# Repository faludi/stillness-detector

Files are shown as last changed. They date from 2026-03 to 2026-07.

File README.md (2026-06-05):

The Stillness Detector senses presence and motion to determine if there is a person standing in front of it and whether that person is currently standing still. It is intended to provide a trigger to interactive art pieces that require stillness rather than action from the viewer. 

See the [DOCUMENTATION](DOCUMENTATION.md) for more information.

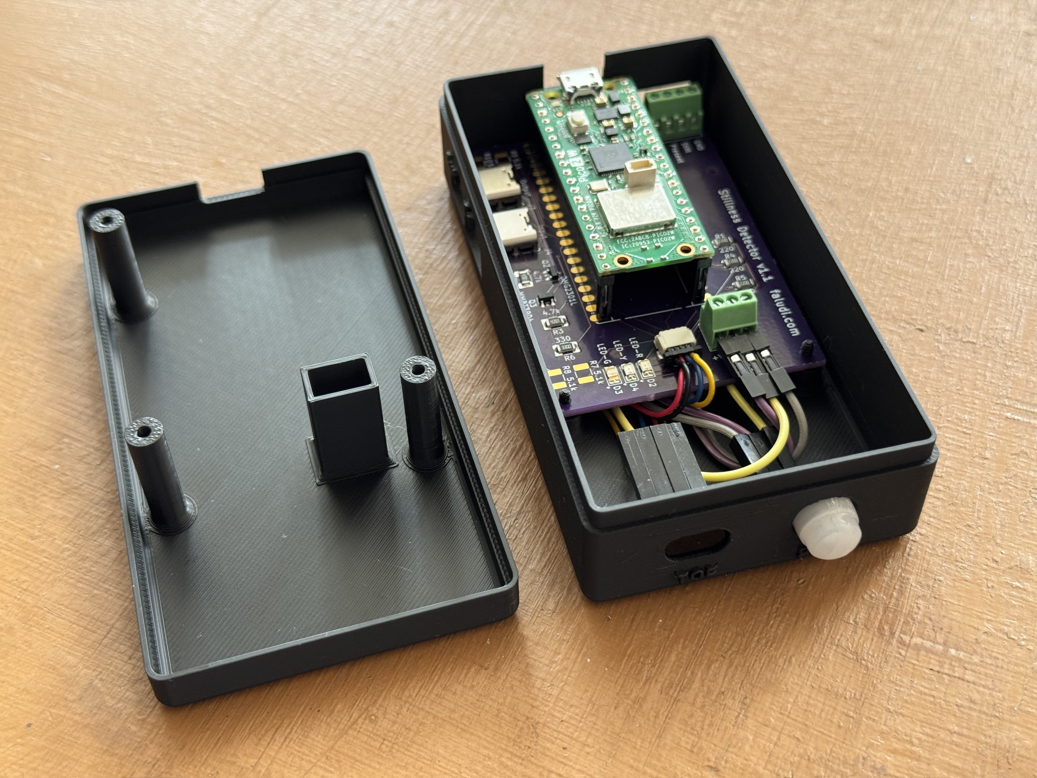
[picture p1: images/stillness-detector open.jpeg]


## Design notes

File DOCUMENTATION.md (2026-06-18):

# Stillness Detector – Documentation

---

## Overview

The **Stillness Detector** is an interactive sensor system that detects whether a person is present and standing still. It is intended for triggering interactive art pieces or installations **only** when a viewer is standing motionless in front of the artwork. The device uses:

- A **time-of-flight distance sensor** (VL53L1X) to measure distance in millimeters
- A **passive infrared (PIR) motion sensor** to detect heat signatures
- A **Raspberry Pi Pico 2** microcontroller to run the logic
- **Status LEDs** and **digital outputs** to trigger external devices (art installations, lights, etc.)

---

## Hardware Quickstart

### *See [Hardware](#hardware) section for design files*

<figure>
    
    <figcaption>Stillness Detector with lid open</figcaption>
</figure>

<figure>
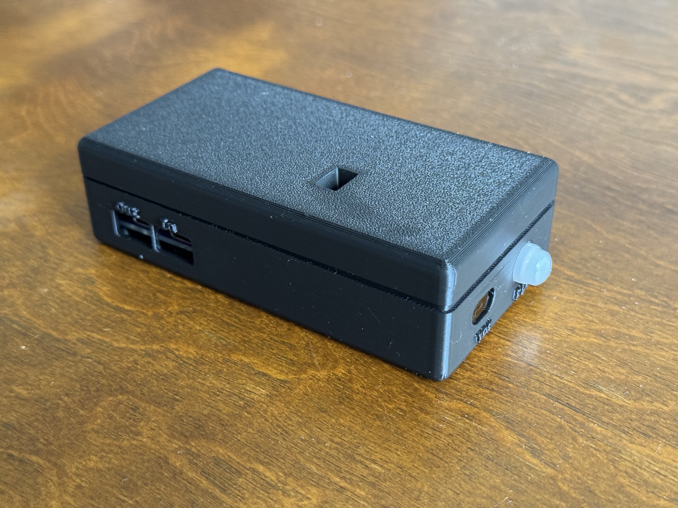
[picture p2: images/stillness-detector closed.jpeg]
    
    <figcaption>Stillness Detector with lid closed</figcaption>
</figure>

1. Power the stillness detector via its USB-micro connector labled "Power"
<figure>
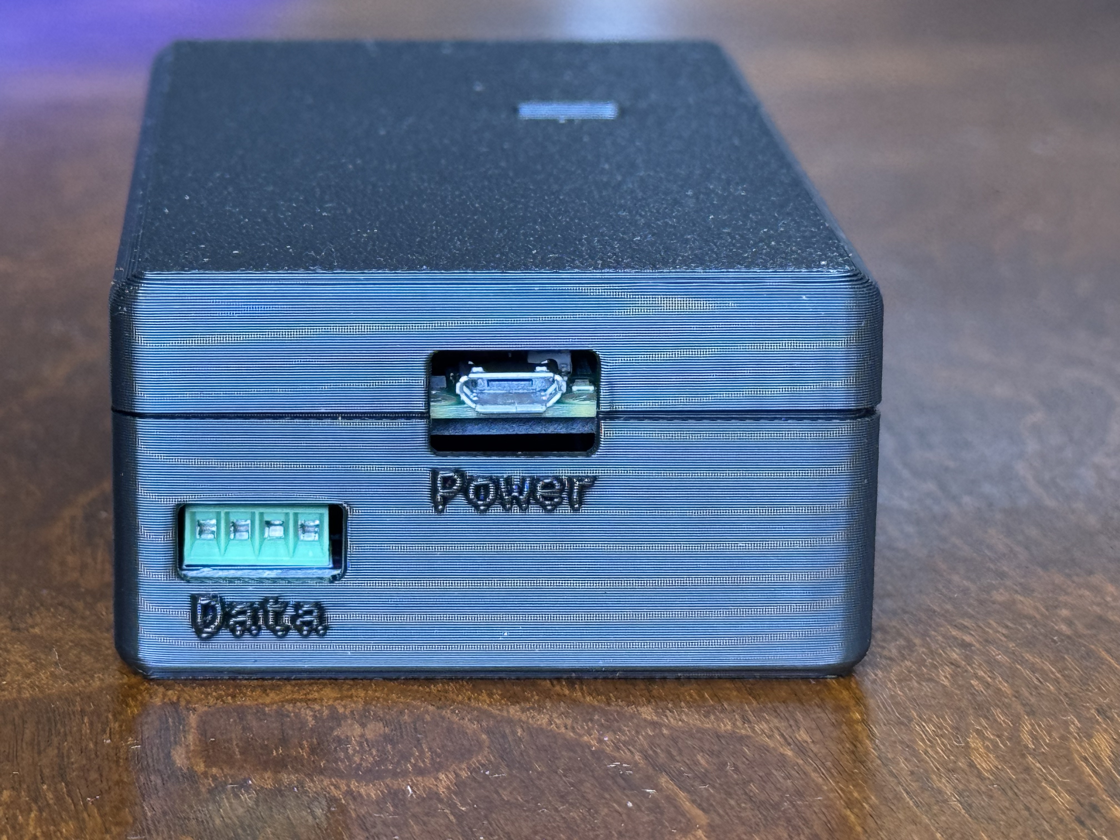
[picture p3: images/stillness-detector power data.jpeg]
    
    <figcaption>Stillness Detector power and data ports</figcaption>
</figure>

2. For controlling USB-C power, attach a power supply to the USB-C port marked "In", and a display device to the USB-C port marked "Out". Your display device will be powered whenever stillness is detected.
<figure>
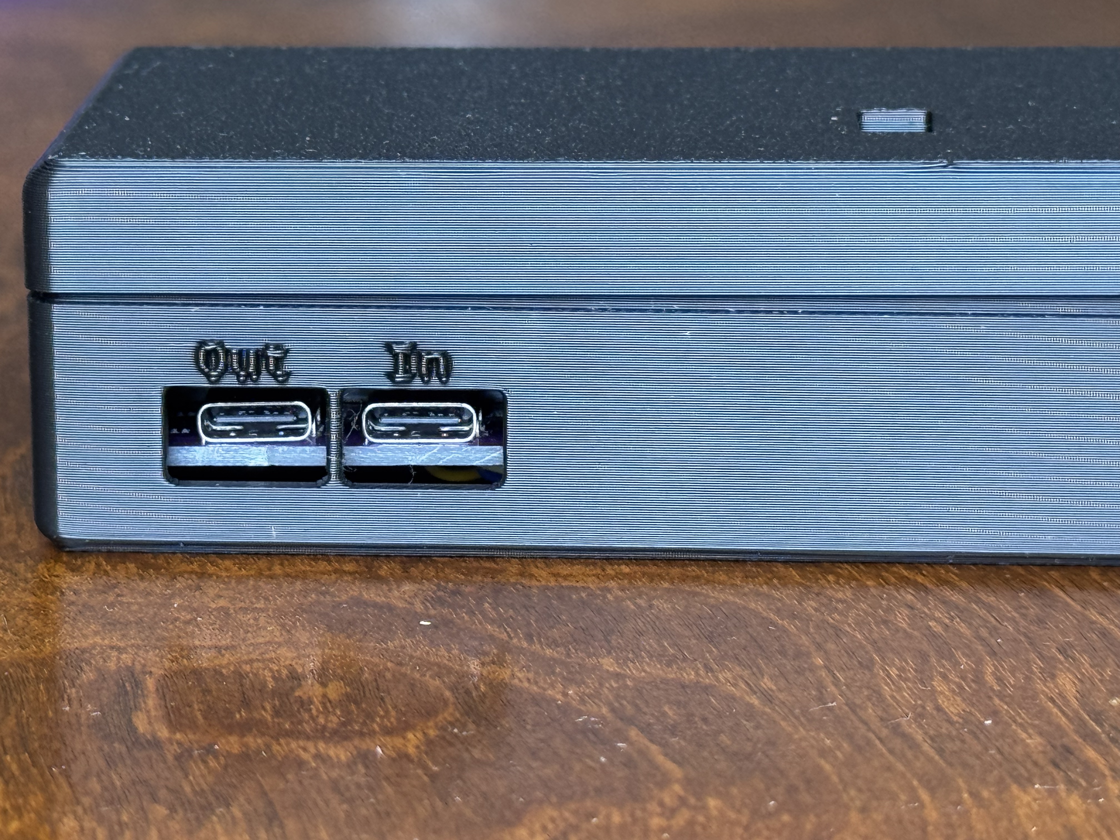
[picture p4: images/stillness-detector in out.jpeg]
    
    <figcaption>Stillness Detector USB-C power control input & output</figcaption>
</figure>

3. For controlling external microcontrollers, attach wires to the "Data" connector. At a minimum use "GND" for common ground and "Still" for output when stillness is detected. You can also use "Absent" which will be active when no person is detected, and "Present" which will be active when a person has been detected but they are not still yet.
<figure>
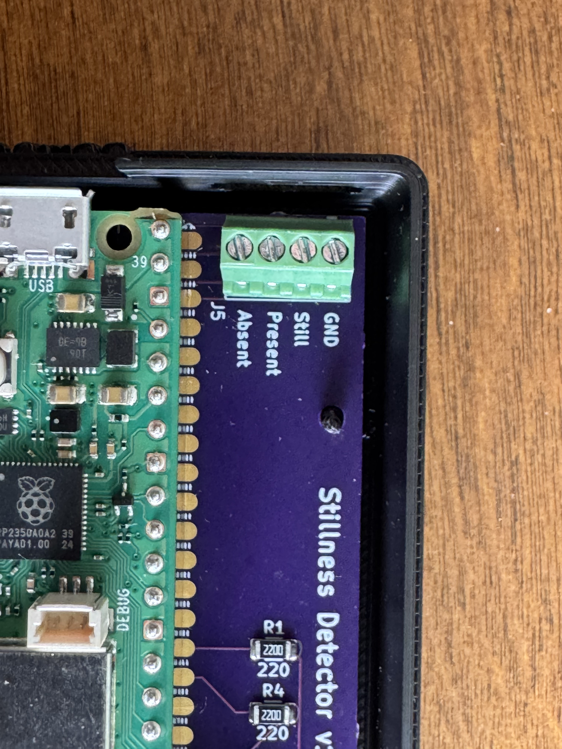
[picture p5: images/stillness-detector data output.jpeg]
    
    <figcaption>Stillness Detector data output connectors</figcaption>
</figure>

4. Orient the Stillness Detector so that that time-of-flight sensor and passive infrared sensor are pointed towards where the viewer will be standing.
<figure>
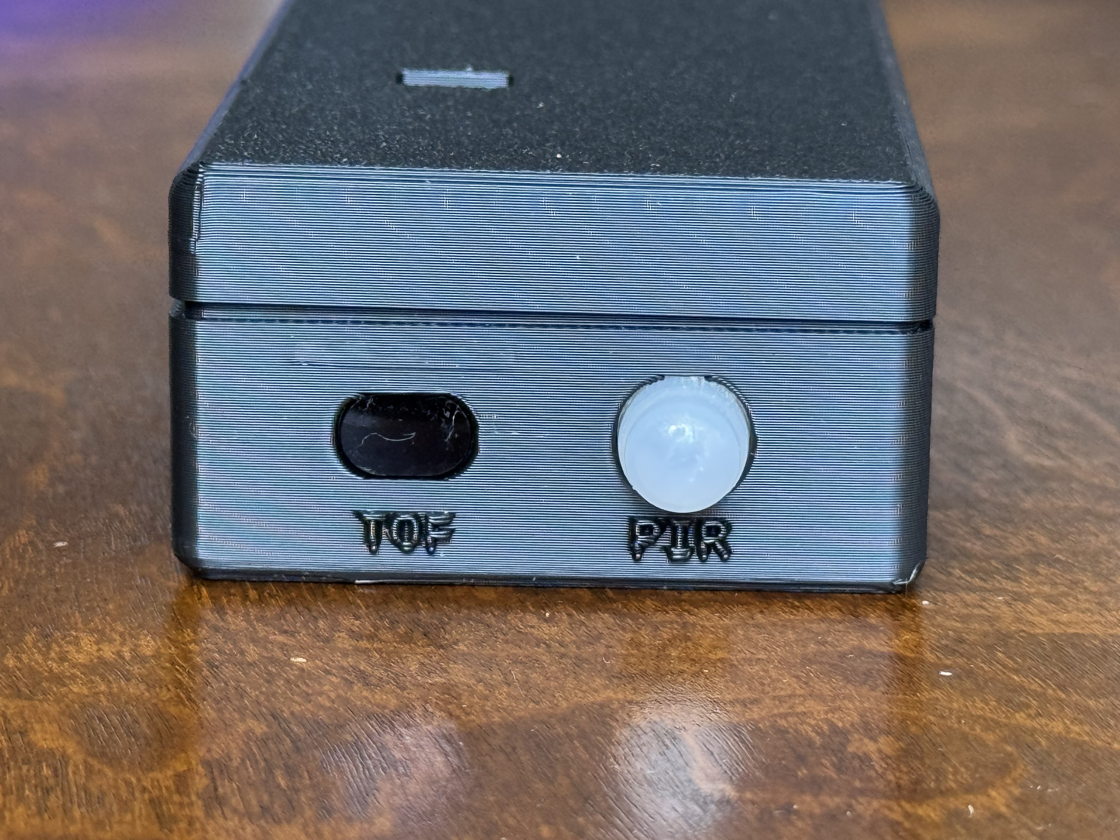
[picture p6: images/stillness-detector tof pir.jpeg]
    
    <figcaption>Stillness Detector time of flight and passive infrared sensors</figcaption>
</figure>

Inside the Stillness Detector is a Raspberry Pi Pico 2 WH with a custom circuit board and sensors.
<figure>
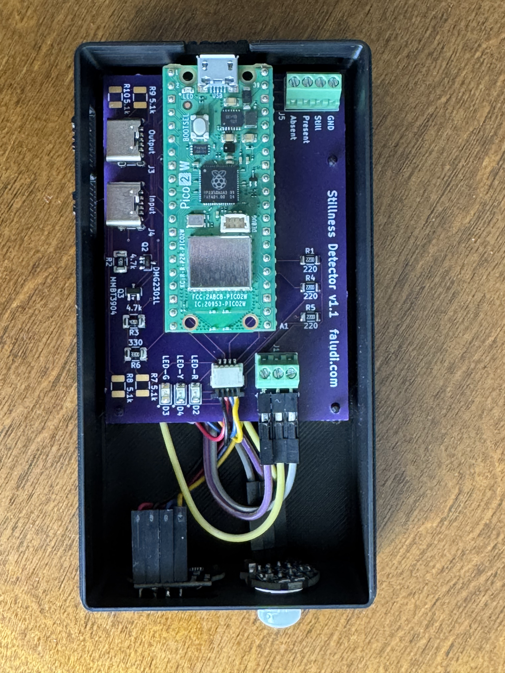
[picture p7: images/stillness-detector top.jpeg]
    
    <figcaption>Stillness Detector top view</figcaption>
</figure>

There are three output LEDs that indicate the detection state, Red when nobody is detected, yellow when a person is present but not yet still, green when they have settled and are motionless. The internal connectors for the sensors are also shown. These are useful if you want to place the sensors outside of the enclosure and need to extend the connector wires. 
<figure>
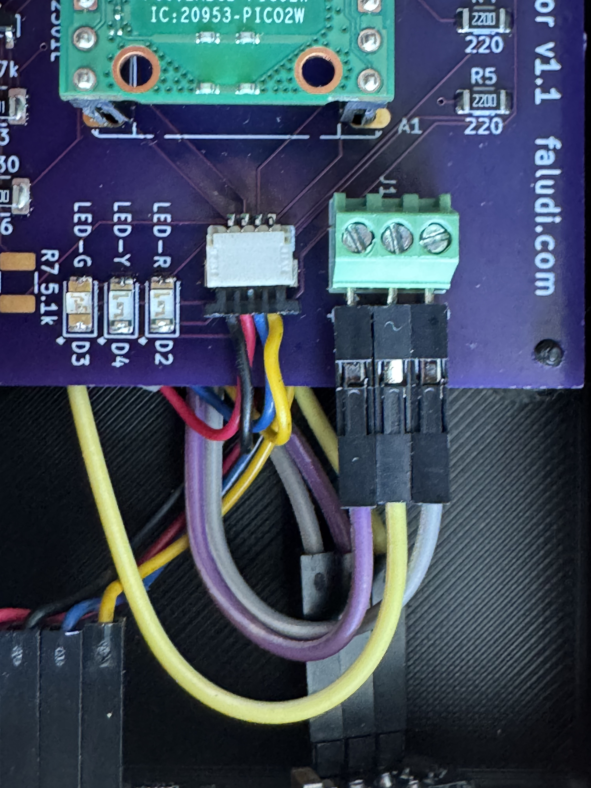
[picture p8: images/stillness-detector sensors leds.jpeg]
    
    <figcaption>Stillness Detector sensor connectors and status LEDs</figcaption>
</figure>

## Software Quickstart

### Installation

1. **Download MicroPython firmware** onto your Pico 2:
   - Visit [micropython.org/download/rp2350](https://micropython.org/download/rp2350)
   - Hold `BOOTSEL` button, plug in USB, drag `.uf2` file to mount

2. **Copy files** to the Pico 2:
   ```
   vl53l1x.py         (sensor driver)
   settings.py        (configuration)
   main.py            (main program)
   ```

3. **Run the program:**
   - The Pico 2 will auto-run `main.py` on startup
   - Or use a serial terminal (e.g., Thonny IDE) and press Ctrl+D to reload

4. **Verify:**
   - Green status LED should blink briefly on startup
   - Aim your hand at the distance sensor; you should see serial output with distance readings

---

## Files & Entry Points

**Repository Structure**

```
stillness-detector/
├── main.py              # Main program logic and event loop
├── vl53l1x.py           # VL53L1X sensor driver (time-of-flight)
├── settings.py          # User-configurable parameters
├── README.md            # Quick reference
├── DOCUMENTATION.md     # This file
├── hardware/            # CAD and circuit design files
│   ├── Stillness_Detector_Enclosure_v1.0.scad
│   ├── stillness-detector.kicad_pcb
│   └── stillness-detector.kicad_sch
└── images/              # Diagrams and photos
```

### File Roles at a Glance

- **`main.py`**: Entry point. Initializes hardware, reads sensors in a loop, applies logic to determine presence/stillness state, and sets output pins.
- **`vl53l1x.py`**: Time-of-flight sensor driver. Handles I2C communication and distance measurements.
- **`settings.py`**: Tuning parameters for sensitivity, delay, and mode presets.

---

## Code Walkthrough

### 1. Initialization (main.py)

When the Pico 2 boots, `main.py` sets up all hardware components. Here's what happens:

**Sensor Setup**

```python
from machine import Pin, I2C
from vl53l1x import VL53L1X
import settings

# Initialize I2C (bus 0 on Pico 2)
i2c = I2C(0)

# Create sensor object; this establishes I2C communication
time_of_flight = VL53L1X(i2c)
```

**What this does:**
- `I2C(0)` creates an I2C bus using GPIO4 (SDA) and GPIO5 (SCL).
- `VL53L1X(i2c)` initializes the sensor driver and sends startup commands to the sensor.

**Why it's written this way:**
- The sensor needs I2C to communicate; both SDA and SCL are on specific pins.
- Wrapping in a try/except (in the real code) allows retries if the sensor isn't ready.

**Pin & LED Setup**

```python
class HardwareInterface:
    """
    Manages all hardware components for the stillness detector.
    
    This class encapsulates:
    - Motion sensor (PIR)
    - Status LED (onboard)
    - RGB LED indicator
    - Digital output pins for external devices
    """
    def __init__(self):
        self.motion_sensor = Pin(PIR_PIN, Pin.IN)
        self.status_led = Pin(STATUS_LED_PIN, Pin.OUT)
        self.rgb_leds = {
            "red": Pin(RED_LED_PIN, Pin.OUT),
            "green": Pin(GREEN_LED_PIN, Pin.OUT),
            "yellow": Pin(YELLOW_LED_PIN, Pin.OUT),
        }
        self.outputs = {
            "absent": Pin(ABSENT_OUTPUT_PIN, Pin.OUT),
            "present": Pin(PRESENT_OUTPUT_PIN, Pin.OUT),
            "still": Pin(STILL_OUTPUT_PIN, Pin.OUT),
        }
```

**What this does:**
- Wraps all pin definitions in a class for organization.
- Sets up three categories: input (motion sensor), debug LEDs, and output signals.

**Why it's written this way:**
- Grouping related pins makes the code easier to test, mock, and maintain.
- The dictionary structure lets you access LEDs by name (e.g., `self.rgb_leds["red"]`).

---

### 2. Configuration & Modes (settings.py)

The detector has three preset modes, plus a custom mode for advanced tuning.

```python
MODE = 'normal'  # options: "normal", "relaxed", "strict", "custom"

# Fallback for custom mode
SETTLING_DELAY = 5              # Seconds before stillness is armed after presence detected
DAMPING_INTERVAL = 7            # Ignore motion events within this interval (seconds)
ALLOWABLE_DISTANCE_CHANGE = 300 # Max movement in mm before stillness is cancelled
```

**Preset Modes**

```python
MODE_PRESETS = {
    "relaxed": {"settling_delay": 3, "damping_interval": 3, "allowable_distance_change": 1000},
    "normal":  {"settling_delay": 5, "damping_interval": 7, "allowable_distance_change": 300},
    "strict":  {"settling_delay": 10, "damping_interval": 20, "allowable_distance_change": 200},
}
```

**What this does:**
- `settling_delay`: How long the person must stand before "stillness" is triggered.
- `damping_interval`: Minimum time between motion events to ignore jitter.
- `allowable_distance_change`: Max forward/backward sway before stillness is lost.

**Why it's written this way:**
- Different art installations need different sensitivity. Presets let users pick without tweaking multiple values.
- `"relaxed"` is forgiving (wiggly people still count as still); `"strict"` requires near-total stillness.

---

### 3. Main Loop (main.py)

The core logic runs continuously:

```python
while True:
    # 1. Read distance from time-of-flight sensor
    distance = time_of_flight.read_distance()
    
    # 2. Check if distance is within detection range
    if MIN_DISTANCE <= distance <= MAX_DISTANCE:
        person_present = True
    else:
        person_present = False
    
    # 3. Check PIR sensor for motion
    motion_detected = motion_sensor.value() == 1  # Active high
    
    # 4. Apply state machine logic (simplified)
    if not person_present:
        state = "absent"
    elif motion_detected and time_since_motion < SETTLING_DELAY:
        state = "present"
    else:
        state = "still"
    
    # 5. Update output pins
    set_output_pins(state)
    
    # 6. Sleep to avoid flooding the loop
    time.sleep(0.1)
```

**What this does:**
- Reads distance and motion in each iteration.
- Compares distance to `MIN_DISTANCE` and `MAX_DISTANCE` from `settings.py`.
- Uses a state machine to determine if the person is absent, present (moving), or still.
- Updates output pins (GP7, GP8, GP9) based on the state.

**Why it's written this way:**
- A continuous loop allows real-time response to sensor changes.
- The state machine is clear: three states map to three output pins, making debugging easy.
- The `time.sleep(0.1)` prevents the loop from running so fast it floods the serial output.

---

### 4. Sensor Driver (vl53l1x.py)

The VL53L1X is a complex sensor. The driver abstracts away the I2C protocol.

**Key Method: `read_distance()`**

```python
def read_distance(self):
    """
    Read the distance in millimeters.
    
    Returns:
        int: Distance measurement in mm, or -1 if measurement failed.
    """
    # Request a new measurement
    self._write_register(RESULT_RANGE, measurement_data)
    
    # Wait for the sensor to be ready
    while not self._is_ready():
        time.sleep(0.001)
    
    # Read the raw distance from I2C
    distance_raw = self._read_register(DISTANCE_HIGH, 2)
    distance_mm = (distance_raw[0] << 8) | distance_raw[1]
    
    return distance_mm
```

**What this does:**
- Sends an I2C command to trigger a distance measurement.
- Waits for the sensor's ready flag (polling).
- Reads two bytes from the sensor (high byte and low byte).
- Combines them into a single 16-bit value.

**Why it's written this way:**
- The sensor requires a specific I2C protocol; this driver hides the complexity.
- MicroPython users can call `sensor.read_distance()` without knowing register addresses.
- The polling loop ensures the sensor has finished before we read the result.

---

**Key Insights**
1. Distance measurement happens on every loop iteration (every 0.1 seconds).
2. The state only changes after `SETTLING_DELAY` to avoid false positives.
3. PIR motion is one factor; distance drift is another (prevents stillness if person shifts by >300mm).
4. Output pins follow the state directly: only one output is active (low) at a time.

---

## Configuration & Tuning

### Quick Adjustments

**To make the detector more forgiving (accept more wiggling):**
```python
MODE = 'relaxed'  # in settings.py
```

**To make it stricter (require absolute stillness):**
```python
MODE = 'strict'
```

**For custom fine-tuning:**

Edit `settings.py`:

```python
MODE = 'custom'

SETTLING_DELAY = 3              # Reduce: person is "still" sooner
DAMPING_INTERVAL = 5            # Reduce: motion events closer together
ALLOWABLE_DISTANCE_CHANGE = 500 # Increase: more wiggle room allowed
```

### Understanding Each Parameter

| Parameter | Unit | Effect | Typical Range |
|---|---|---|---|
| `SETTLING_DELAY` | seconds | Time before stillness is triggered after presence detected | 2–10 |
| `DAMPING_INTERVAL` | seconds | Minimum gap between motion events to filter noise | 3–20 |
| `ALLOWABLE_DISTANCE_CHANGE` | mm | Max forward/backward sway before stillness lost | 100–1000 |
| `MIN_DISTANCE` | mm | Nearest detection range (person too close = not detected) | 200–500 |
| `MAX_DISTANCE` | mm | Farthest detection range (person too far = not detected) | 1000–3000 |
| `PIR_RESET_TIME` | seconds | Duration of a PIR trigger (from data sheet or testing) | 1-4 |

### Tuning Tips

1. **Test your sensor range first:**
   - Connect to serial terminal (e.g., Thonny).
   - Observe `distance` every iteration.
   - Stand at different distances; note the readings.
   - Set `MIN_DISTANCE` and `MAX_DISTANCE` accordingly.

2. **Calibrate for motion sensitivity:**
   - Use `"strict"` mode initially.
   - Gradually relax if false negatives occur (stillness not triggered).
   - Reduce `ALLOWABLE_DISTANCE_CHANGE` if wiggling cancels stillness too often.

3. **Adjust settling time for UX:**
   - Shorter `SETTLING_DELAY` = faster trigger (snappier response).
   - Longer `SETTLING_DELAY` = more natural (person settles naturally).
   - 5 seconds is a good starting point.

---

## API Reference

### VL53L1X Driver (`vl53l1x.py`)

#### `VL53L1X(i2c_bus, address=0x29)`
Initialize the time-of-flight sensor.

**Parameters:**
- `i2c_bus`: MicroPython I2C object (e.g., `I2C(0)`)
- `address`: I2C address of the sensor (default: 0x29 for Adafruit module)

**Raises:** `OSError` if sensor not found on I2C bus.

**Example:**
```python
from machine import I2C
from vl53l1x import VL53L1X

i2c = I2C(0)
sensor = VL53L1X(i2c)
```

---

#### `read_distance()`
Perform a single distance measurement.

**Returns:**
- `int`: Distance in millimeters. Range: 0–4000 mm (typical).
- Returns `-1` if measurement failed.

**Example:**
```python
distance = sensor.read_distance()
if distance > 0:
    print(f"Distance: {distance} mm")
```

---

### Hardware Interface (`main.py` – `HardwareInterface` Class)

#### `set_led(color, state)`
Control a single RGB LED.

**Parameters:**
- `color`: `"red"`, `"green"`, or `"yellow"`
- `state`: `1` (off, active-low) or `0` (on)

**Example:**
```python
hw = HardwareInterface()
hw.set_led("red", 0)    # Turn red LED on
hw.set_led("red", 1)    # Turn red LED off
```

---

#### `set_output(output_name, state)`
Control an external output pin.

**Parameters:**
- `output_name`: `"absent"`, `"present"`, or `"still"`
- `state`: `1` (high, inactive) or `0` (low, active)

**Example:**
```python
hw.set_output("still", 0)  # Trigger the "still" output pin
```

---

## Troubleshooting & FAQ

### Problem: "Failed to initialize VL53L1X"

**Possible causes:**
1. Sensor not connected or wired incorrectly.
2. I2C lines (SDA/SCL) not pulled to 3.3V or shorted to GND.
3. Wrong I2C address.

**Debug steps:**
1. Double-check wiring: SDA → GP4, SCL → GP5, GND → GND, VCC → 3.3V.
2. Run an I2C scan to find the sensor address:
   ```python
   from machine import I2C
   i2c = I2C(0)
   devices = i2c.scan()
   print("I2C devices found:", [hex(d) for d in devices])
   ```
   Expected: `[0x29]` (VL53L1X) should appear.
3. If no devices found, check pull-up resistors on SDA/SCL (should be 4.7kΩ to 3.3V).

---

### Problem: Stillness never triggers (always "present")

**Possible causes:**
1. PIR sensor is misconfigured or not responding.
2. `SETTLING_DELAY` is too long.
3. Motion noise is constantly re-triggering.

**Debug steps:**
1. Print the state of the PIR sensor:
   ```python
   print(f"PIR value: {motion_sensor.value()}")
   ```
   Should read `0` when no motion, `1` when motion detected.
2. Reduce `SETTLING_DELAY` to 1–2 seconds and test.
3. Increase `DAMPING_INTERVAL` to filter noise.

---

### Problem: Distance readings are erratic or jump around

**Possible causes:**
1. Reflective surface or interference in front of sensor.
2. I2C timing issue (loose connection).
3. Too much electromagnetic noise.

**Debug steps:**
1. Move the sensor to a clear area with a matte (non-reflective) target.
2. Check all I2C connections; re-seat the sensor.
3. Add a filter: average the last 3 readings:
   ```python
   readings = []
   while len(readings) < 3:
       readings.append(time_of_flight.read_distance())
       time.sleep(0.05)
   smoothed_distance = sum(readings) // len(readings)
   ```

---

### FAQ

**Q: Can I increase the detection range to 5 meters?**

A: The VL53L1X sensor's typical max range is 2–3 meters outdoors. The driver limits it to 4000 mm. You can try:
```python
MAX_DISTANCE = 4000
```
But be aware: at long distances, accuracy drops, and false positives increase. Outdoor performance is worse than indoors.

---

**Q: How can I trigger multiple actions based on presence/still state?**

A: The three output pins (`ABSENT_OUTPUT`, `PRESENT_OUTPUT`, `STILL_OUTPUT`) can be wired to relays, MOSFETs, or other circuits. For example:
- Connect `STILL_OUTPUT` to a relay that turns on lights.
- Connect `PRESENT_OUTPUT` to a different relay that plays a sound.

Only one output is active at a time, so you can switch behaviors based on which pin goes high.

---

**Q: How do I modify the code to log data to a file?**

A: MicroPython supports file I/O on the Pico 2. Add this to `main.py`:

```python
with open("log.txt", "a") as f:  # "a" = append mode
    f.write(f"{time.time()},{distance},{state}\n")
```

Later, download `log.txt` from the Pico 2's storage via a serial connection.

---

**Q: Can I run this on a Raspberry Pi Zero or 4 instead?**

A: Yes, with modifications:
- Raspberry Pi runs full Linux + Python, not MicroPython.
- Use `board` and `busio` libraries instead of `machine` and `I2C`.
- Adapt pin names (e.g., `"GPIO3"` vs `Pin(3)`).
- The logic remains the same.

---

# Hardware

## Appendix A: Design Files

**Enclosure (CAD):**
- File: `hardware/Stillness_Detector_Enclosure_v1.0.scad`
- Format: OpenSCAD parametric design
- Use: 3D print or adapt dimensions for custom housing

**PCB (Circuit Design):**
- Files: `hardware/stillness-detector.kicad_sch` (schematic), `hardware/stillness-detector.kicad_pcb` (layout)
- Format: KiCad 8.0+
- Use: Order custom PCBs via JLCPCB, OSH Park, or similar

---
## Appendix B: Bill of Materials (BOM)

| Part | Quantity | Designation | Cost | Extended Cost | Supplier | Supplier and ref |
| --- | --- | --- | --- | --- | --- | --- |
| USB-C Receptacle TopMnt Horizontal | 2 | USB_C_PowerOnly | $0.60 | $1.20 | Digi-Key | 2073-USB4125-GF-A-0190CT-ND |
| NPN transistor | 1 | MMBT3904 | $0.07 | $0.07 | Digi-Key | 4878-MMBT3904CT-ND |
| 1206 resistor | 4 | 5.1k | $0.05 | $0.19 | Digi-Key | 311-5.10KFRCT-ND |
| 1206 resistor | 1 | 330 | $0.01 | $0.01 | Digi-Key | 311-330FRCT-ND |
| 1206 resistor | 3 | 220 | $0.01 | $0.03 | Digi-Key | 311-220FRCT-ND |
| 1206 resistor | 2 | 4.7k | $0.01 | $0.02 | Digi-Key | 311-4.70KFRCT-ND |
| MOSFET | 1 | DMG2301L | $0.16 | $0.16 | Digi-Key | DMG2301L-7DICT-ND |
| 4-pin terminal block | 1 | Screw_Terminal_01x04 | $1.63 | $1.63 | Digi-Key | ED10563-ND |
| Qwiic connector | 1 | Qwiic_RA | $0.42 | $0.42 | Digi-Key | 455-SM04B-SRSS-TBCT-ND |
| 3-pin terminal block | 1 | PIR Sensor Screw_Terminal_01x03 | $1.26 | $1.26 | Digi-Key | ED10562-ND |
| 1206 LED - yellow | 1 | LED-Y | $0.13 | $0.13 | Digi-Key | 160-1406-1-ND |
| 1206 LED - green | 1 | LED-G | $0.09 | $0.09 | Digi-Key | 160-1456-1-ND |
| 1206 LED - red | 1 | LED-R | $0.09 | $0.09 | Digi-Key | 160-1168-1-ND |
| Raspberry Pi Pico 2 WH | 1 | Raspberry Pi Pico 2 WH | $8.00 | $8.00 | Digi-Key | 2648-SC1634-ND |
| Female headers 20-pin for Pico | 2 | 20-position Female header | $0.85 | $1.70 | Digi-Key | 21601X20GSE |
| PIR Sensor | 1 | SR602 PIR | $2.00 | $2.00 | Amazon | B0FQ4ZXRZS |
| TOF Sensor | 1 | ACEIRMC TOF400C | $5.47 | $5.47 | Amazon | B0DC6M6G7W |
| PIR cables | 3 | F - M | $0.12 | $0.37 | Digi-Key | 1528-1161-ND |
| TOF cable Qwiic | 1 | Qwiic - male pins | $1.95 | $1.95 | Digi-Key | 1568-17912-ND |
| PCB | 1 |  | $8.92 | $8.92 | OSH Park | https://oshpark.com/shared_projects/h9REVbJo |

## Appendix C: Pinout Table

| Pin | Name | Direction | Purpose | Notes |
|-----|---|---|---|---|
| GP3 | PIR | Input | Motion sensor | Digital input; reads 1 when motion detected |
| GP4 | SDA | I/O | I2C data | Time-of-flight sensor communication |
| GP5 | SCL | I/O | I2C clock | Time-of-flight sensor communication |
| GP7 | ABSENT_OUTPUT | Output | External trigger | High when nobody detected |
| GP8 | PRESENT_OUTPUT | Output | External trigger | High when person detected but moving |
| GP9 | STILL_OUTPUT | Output | External trigger | High when stillness detected |
| GP18 | Red LED | Output | Debug indicator | Active-low (0=on) |
| GP19 | Green LED | Output | Debug indicator | Active-low (0=on) |
| GP20 | Yellow LED | Output | Debug indicator | Active-low (0=on) |
| 3.3V | Power | Supply | Sensors & LEDs | All components use 3.3V |
| GND | Ground | Supply | Common reference | Connect to all grounds |

---

## Appendix D: Breadboard diagram<br>

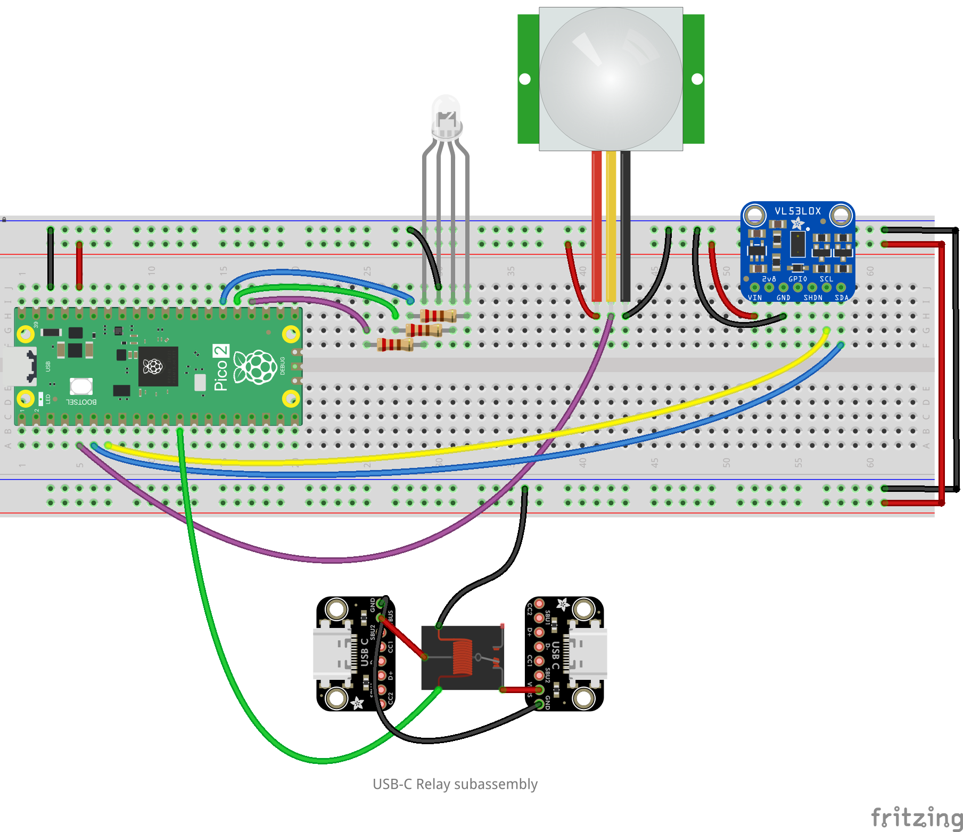
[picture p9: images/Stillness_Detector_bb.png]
Stillness Detector breadboard diagram


## Appendix E: Schematic<br>
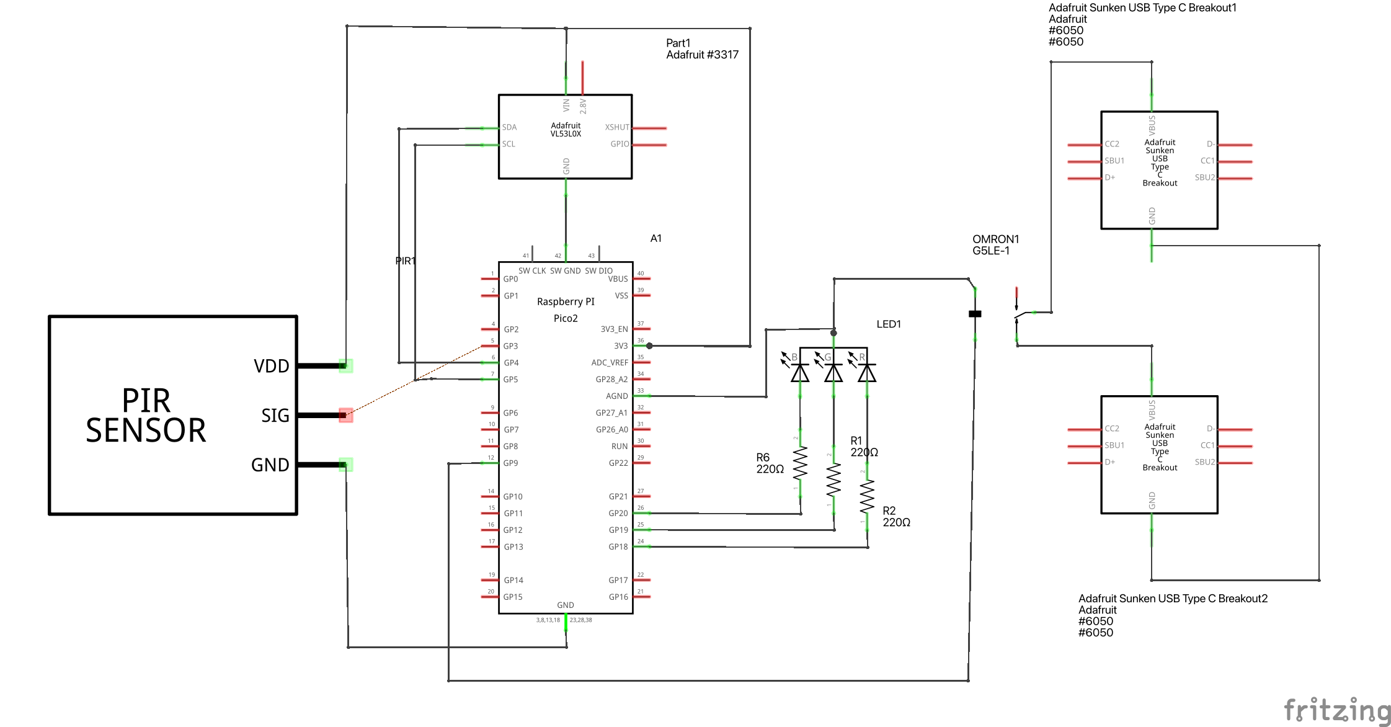
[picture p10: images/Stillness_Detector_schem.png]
Stillness Detector schematic


*\* images created with Fritzing.*

## Appendix F: License & Credits

See [LICENSE](LICENSE) for full text.

This project uses:
- **MicroPython**: [micropython.org](https://micropython.org)
- **VL53L1X driver**: [github.com/drakxtwo/vl53l1x_pico](https://github.com/drakxtwo/vl53l1x_pico)

---

## Appendix G: Contributing

To report bugs or suggest improvements:

1. Test your changes locally first (use Thonny or similar).
2. Document any new settings with their effect and range.
3. Add a code comment explaining non-obvious logic.
4. Update this documentation if adding features.

For Pull Requests: Include a brief description of what changed and why.

---

**Questions?** Check the [Troubleshooting](#troubleshooting--faq) section or file an issue on GitHub.

Happy tinkering! 🎨

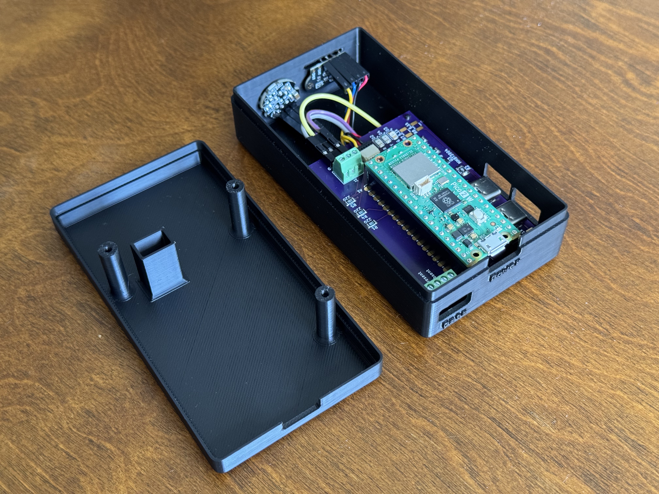
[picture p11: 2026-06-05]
images/stillness-detector left.jpeg

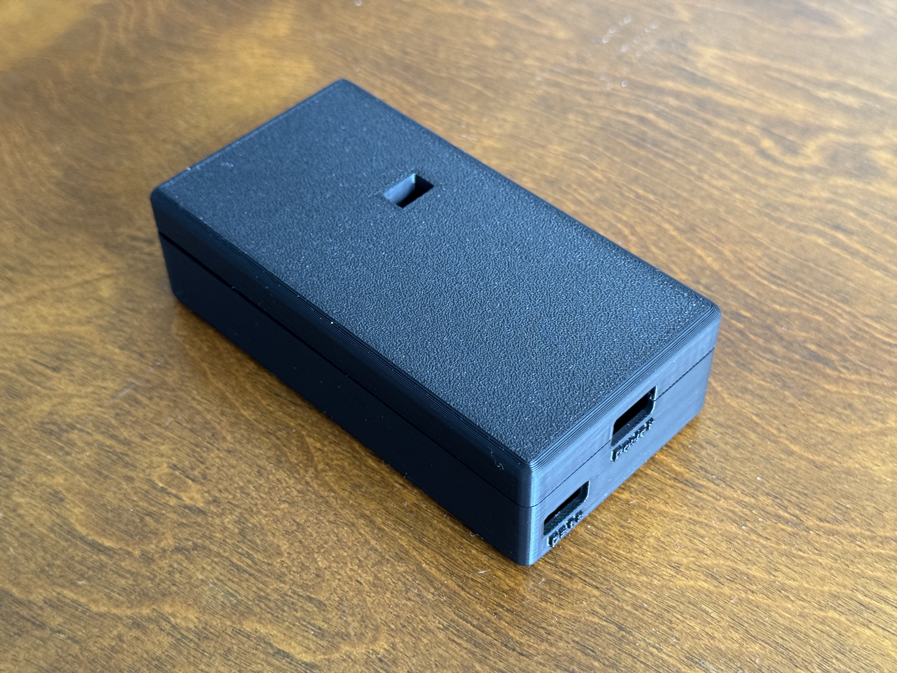
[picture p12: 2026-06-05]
images/stillness-detector back.jpeg

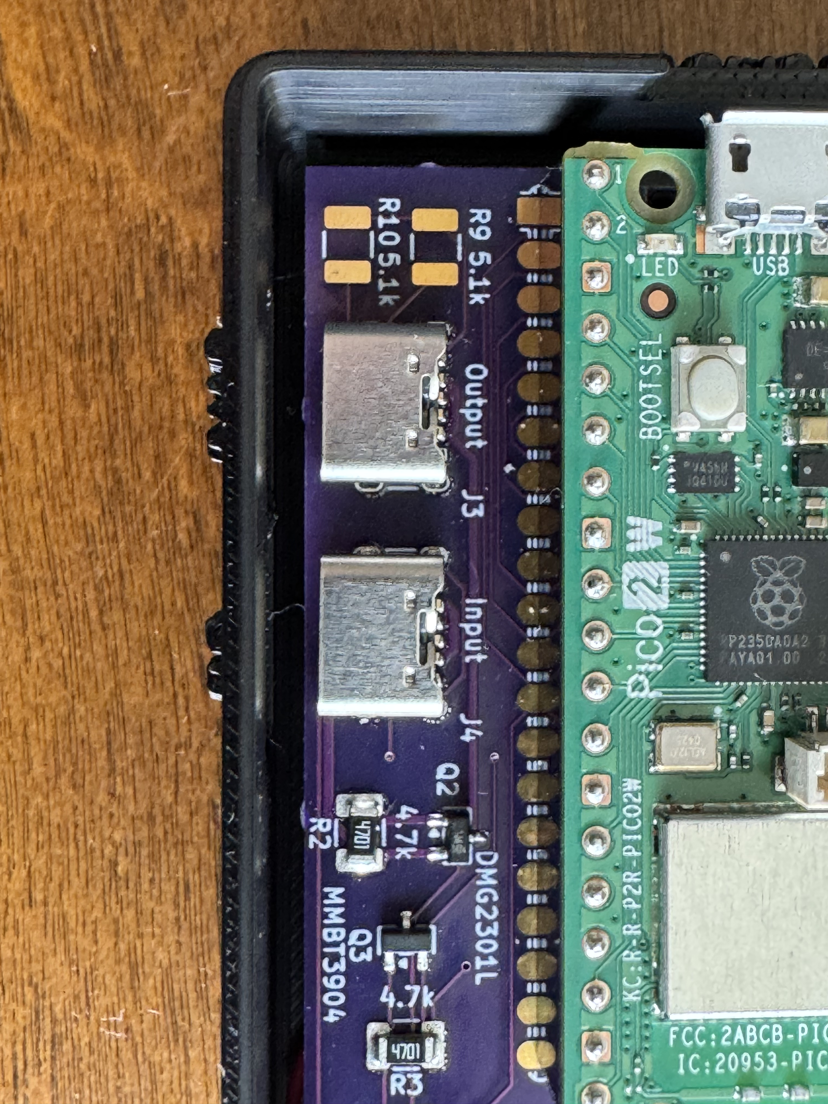
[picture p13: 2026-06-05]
images/stillness-detector USB-C.jpeg

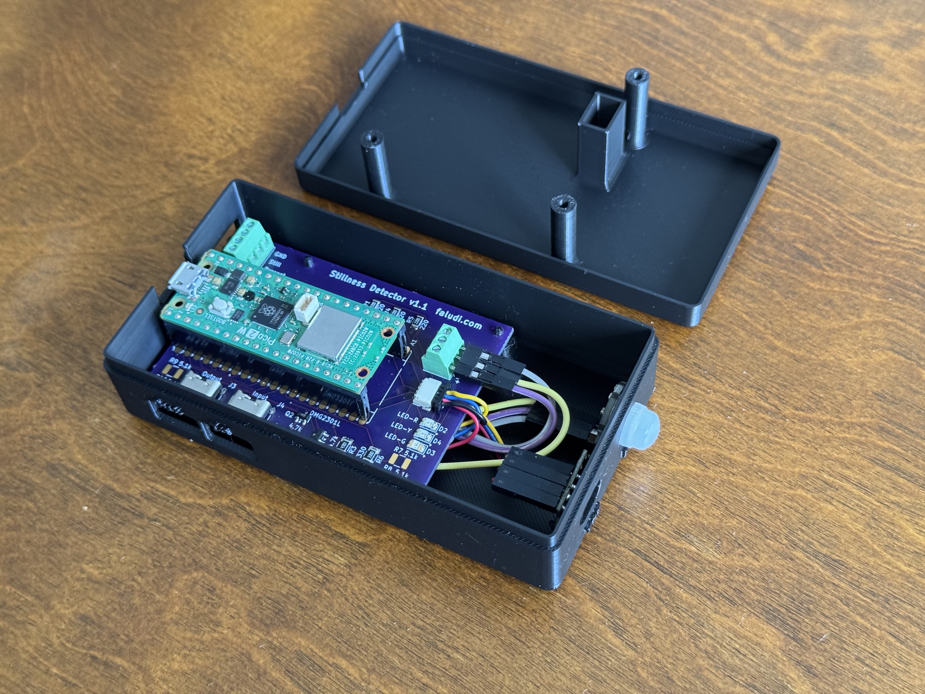
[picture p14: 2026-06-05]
images/stillness-detector right.jpeg

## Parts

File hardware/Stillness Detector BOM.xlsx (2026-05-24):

Id | Designator | Footprint | Quantity | Q x 10 | Designation | Cost | Extended Cost |  | Supplier and ref
1 | J3,J4 | USB_C_Receptacle_GCT_USB4125-xx-x-0190_6P_TopMnt_Horizontal | 2 | 20 | USB_C_PowerOnly | $0.60 | $1.20 | Digi-Key | 2073-USB4125-GF-A-0190CT-ND
2 | Q3 | SOT-23 | 1 | 10 | MMBT3904 | $0.07 | $0.07 | Digi-Key | 4878-MMBT3904CT-ND
 | R7-10 | R_1210_3225Metric_Pad1.30x2.65mm_HandSolder | 4 | 40 | 5.1k | $0.05 | $0.19 | Digi-Key | 311-5.10KFRCT-ND
3 | R6 | R_1210_3225Metric_Pad1.30x2.65mm_HandSolder | 1 | 10 | 330 | $0.01 | $0.01 | Digi-Key | 311-330FRCT-ND
4 | R5,R4,R1 | R_1206_3216Metric | 3 | 30 | 220 | $0.01 | $0.03 | Digi-Key | 311-220FRCT-ND
5 | R3,R2 | R_1210_3225Metric_Pad1.30x2.65mm_HandSolder | 2 | 20 | 4.7k | $0.01 | $0.02 | Digi-Key | 311-4.70KFRCT-ND
6 | Q2 | SOT-23 | 1 | 10 | DMG2301L | $0.16 | $0.16 | Digi-Key | DMG2301L-7DICT-ND
7 | J5 | TerminalBlock_Xinya_XY308-2.54-4P_1x04_P2.54mm_Horizontal | 1 | 10 | Screw_Terminal_01x04 | $1.63 | $1.63 | Digi-Key | ED10563-ND
8 | J2 | JST_1x04_P1.0mm_Horizontal_SMD | 1 | 10 | Qwiic_RA | $0.42 | $0.42 | Digi-Key | 455-SM04B-SRSS-TBCT-ND
9 | J1 | TerminalBlock_Xinya_XY308-2.54-3P_1x03_P2.54mm_Horizontal | 1 | 10 | PIR Sensor Screw_Terminal_01x03 | $1.26 | $1.26 | Digi-Key | ED10562-ND
10 | D4 | LED_1206_3216Metric | 1 | 10 | LED-Y | $0.12 | $0.12 | Digi-Key | 160-1406-1-ND
11 | D3 | LED_1206_3216Metric | 1 | 10 | LED-G | $0.09 | $0.09 | Digi-Key | 160-1456-1-ND
12 | D2 | LED_1206_3216Metric | 1 | 10 | LED-R | $0.09 | $0.09 | Digi-Key | 160-1168-1-ND
13 | A1 | RaspberryPi_Pico_Common_Unspecified | 1 | 10 | Raspberry Pi Pico 2 WH | $8.00 | $8.00 | Digi-Key | 2648-SC1634-ND
 |  | Female headers 20-pin for Pico | 2 | 20 | 20-position Female header | $0.85 | $1.70 | Digi-Key | 21601X20GSE
 |  | PIR Sensor | 1 | 10 | SR602 PIR | $2.00 | $2.00 | Amazon | B096NZ4P3K
 |  | TOF Sensor | 1 | 10 | ACEIRMC TOF400C | $5.47 | $5.47 | Amazon | B0FQ4ZXRZS
 |  | PIR cables | 3 | 30 | F - M | $0.12 | $0.37 | Digi-Key | 1528-1161-ND
 |  | TOF cables | 4 | 40 | F - M | $0.12 | $0.50 | Digi-Key | 1528-1161-ND
 |  | PCB | 1 | 10 |  | $16.05 | $16.05 | OSH Park | https://oshpark.com/shared_projects/h9REVbJo
 |  |  |  |  |  |  | $39.39

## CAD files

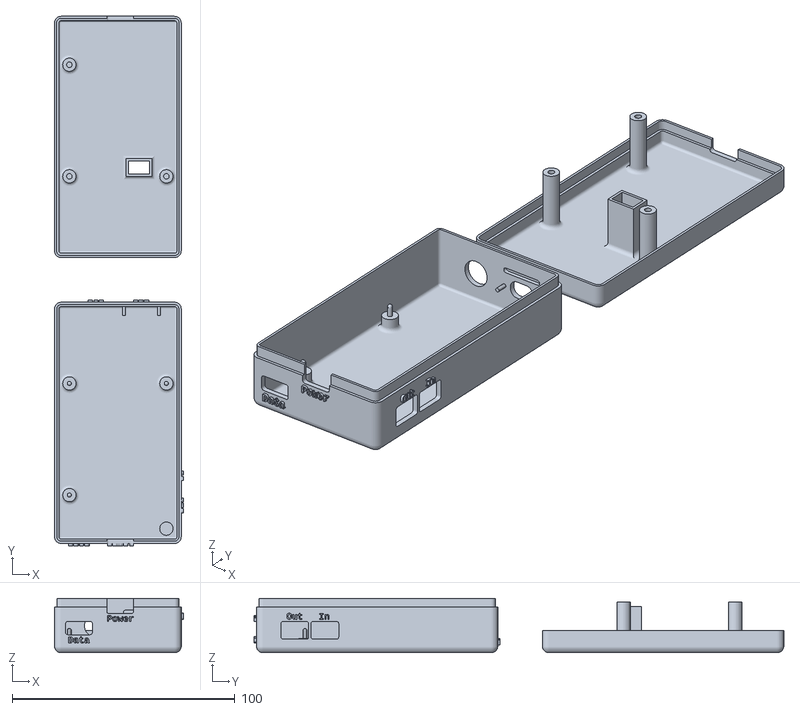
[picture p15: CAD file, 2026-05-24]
hardware/Stillness_Detector_Enclosure_v1.0.stl
58.0 x 238.0 x 24.5

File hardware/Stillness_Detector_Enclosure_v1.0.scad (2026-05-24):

//-----------------------------------------------------------------------
// Yet Another Parameterized Projectbox generator
//
//  This is a box for <template>
//
//  Version 3.0.1 (2024-01-15)
//
// This design is parameterized based on the size of a PCB.
//
// For many/complex cutoutGrills, you might need to adjust
//  the max number of elements in OpenSCAD:
//
//      Preferences->Advanced->Turn off rendering at 250000 elements
//                                                   ^^^^^^
//
//-----------------------------------------------------------------------

include <./library/YAPPgenerator_v3.scad>

//---------------------------------------------------------
// This design is parameterized based on the size of a PCB.
//---------------------------------------------------------
// Note: length/lengte refers to X axis, 
//       width/breedte refers to Y axis,
//       height/hoogte refers to Z axis

/*
      padding-back|<------pcb length --->|<padding-front
                            RIGHT
        0    X-axis ---> 
        +----------------------------------------+   ---
        |                                        |    ^
        |                                        |   padding-right 
      Y |                                        |    v
      | |    -5,y +----------------------+       |   ---              
 B    a |         | 0,y              x,y |       |     ^              F
 A    x |         |                      |       |     |              R
 C    i |         |                      |       |     | pcb width    O
 K    s |         |                      |       |     |              N
        |         | 0,0              x,0 |       |     v              T
      ^ |    -5,0 +----------------------+       |   ---
      | |                                        |    padding-left
      0 +----------------------------------------+   ---
        0    X-as --->
                          LEFT
*/


//-- which part(s) do you want to print?
printBaseShell        = true;
printLidShell         = true;
printSwitchExtenders  = true;


//-- pcb dimensions -- very important!!!
pcbLength           = 49; // front to back (X axis)
pcbWidth            = 70.5; // side to side (Y axis)
pcbThickness        = 1.6;
                            
//-- padding between pcb and inside wall
paddingFront        = 2;
paddingBack         = 2;
paddingRight        = 32;
paddingLeft         = 2;

//-- Edit these parameters for your own box dimensions
wallThickness       = 2.0;
basePlaneThickness  = 1.5;
lidPlaneThickness   = 1.5;

//-- Total height of box = lidPlaneThickness 
//                       + lidWallHeight 
//--                     + baseWallHeight 
//                       + basePlaneThickness
//-- space between pcb and lidPlane :=
//--      (bottonWallHeight+lidWallHeight) - (standoffHeight+pcbThickness)
baseWallHeight      = 23;
lidWallHeight       = 5;

//-- ridge where base and lid off box can overlap
//-- Make sure this isn't less than lidWallHeight
ridgeHeight         = 4.0;
ridgeSlack          = 0.2;
roundRadius         = 3.0;

//-- How much the PCB needs to be raised from the base
//-- to leave room for solderings and whatnot
standoffHeight      = 5.0;  //-- used for PCB Supports, Push Button and showPCB
standoffDiameter    = 6;
standoffPinDiameter = 1.9;
standoffHoleSlack   = 0.6;

// Set the layer height of your printer
printerLayerHeight  = 0.2;


//---------------------------
//--     C O N T R O L     --
//---------------------------
// -- Render --
renderQuality             = 8;          //-> from 1 to 32, Default = 8

// --Preview --
previewQuality            = 5;          //-> from 1 to 32, Default = 5
showSideBySide            = true;       //-> Default = true
onLidGap                  = 0;  // tip don't override to animate the lid opening
colorLid                  = "YellowGreen";   
alphaLid                  = 1;
colorBase                 = "BurlyWood";
alphaBase                 = 1;
hideLidWalls              = false;      //-> Remove the walls from the lid : only if preview and showSideBySide=true 
hideBaseWalls             = false;      //-> Remove the walls from the base : only if preview and showSideBySide=true  
showOrientation           = true;       //-> Show the Front/Back/Left/Right labels : only in preview
showPCB                   = true;      //-> Show the PCB in red : only in preview 
showSwitches              = false;      //-> Show the switches (for pushbuttons) : only in preview 
showButtonsDepressed      = false;      //-> Should the buttons in the Lid On view be in the pressed position
showOriginCoordBox        = true;      //-> Shows red bars representing the origin for yappCoordBox : only in preview 
showOriginCoordBoxInside  = false;      //-> Shows blue bars representing the origin for yappCoordBoxInside : only in preview 
showOriginCoordPCB        = false;      //-> Shows blue bars representing the origin for yappCoordBoxInside : only in preview 
showMarkersPCB            = false;      //-> Shows black bars corners of the PCB : only in preview 
showMarkersCenter         = false;      //-> Shows magenta bars along the centers of all faces  
inspectX                  = 0;          //-> 0=none (>0 from Back)
inspectY                  = 0;          //-> 0=none (>0 from Right)
inspectZ                  = 0;          //-> 0=none (>0 from Bottom)
inspectXfromBack          = true;       //-> View from the inspection cut foreward
inspectYfromLeft          = true;       //-> View from the inspection cut to the right
inspectZfromBottom        = true;       //-> View from the inspection cut up
//---------------------------
//--     C O N T R O L     --
//---------------------------

//-------------------------------------------------------------------
//-------------------------------------------------------------------
// Start of Debugging config (used if not overridden in template)
// ------------------------------------------------------------------
// ------------------------------------------------------------------

//==================================================================
//  *** Shapes ***
//------------------------------------------------------------------
//  There are a view pre defines shapes and masks
//  shapes:
//      shapeIsoTriangle, shapeHexagon, shape6ptStar
//
//  masks:
//      maskHoneycomb, maskHexCircles, maskBars, maskOffsetBars
//
//------------------------------------------------------------------
// Shapes should be defined to fit into a 1x1 box (+/-0.5 in X and Y) - they will 
// be scaled as needed.
// defined as a vector of [x,y] vertices pairs.(min 3 vertices)
// for example a triangle could be [yappPolygonDef,[[-0.5,-0.5],[0,0.5],[0.5,-0.5]]];
// To see how to add your own shapes and mask see the YAPPgenerator program
//------------------------------------------------------------------


// Show sample of a Mask
//SampleMask(maskHoneycomb);

//===================================================================
// *** PCB Supports ***
// Pin and Socket standoffs 
//-------------------------------------------------------------------
//  Default origin =  yappCoordPCB : pcb[0,0,0]
//
//  Parameters:
//   Required:
//    p(0) = posx
//    p(1) = posy
//   Optional:
//    p(2) = Height to bottom of PCB : Default = standoffHeight
//    p(3) = PCB Gap : Default = -1 : Default for yappCoordPCB=pcbThickness, yappCoordBox=0
//    p(4) = standoffDiameter    Default = standoffDiameter;
//    p(5) = standoffPinDiameter Default = standoffPinDiameter;
//    p(6) = standoffHoleSlack   Default = standoffHoleSlack;
//    p(7) = filletRadius (0 = auto size)
//    n(a) = { <yappBoth> | yappLidOnly | yappBaseOnly }
//    n(b) = { <yappPin>, yappHole } // Baseplate support treatment
//    n(c) = { <yappAllCorners>, yappFrontLeft | yappFrontRight | yappBackLeft | yappBackRight }
//    n(d) = { <yappCoordPCB> | yappCoordBox | yappCoordBoxInside }
//    n(e) = { yappNoFillet }
//-------------------------------------------------------------------
pcbStands = 
[
//- Add three stands with pins and one without
    [2.7,17.8],
    [2.7, 67.96],
    [46.3, 67.96],
//    [46.3, 2.7, standoffHeight,-1,standoffDiameter,standoffPinDiameter-1,standoffHoleSlack,0,0, yappBaseOnly,yappPin]
//-   Add posts 25mm from the corners of the box, with a custon height,diameter, Pin Size, hole
//-   slack and filler radius.
//  [25, 25, 10, 10, 3.3, 0.9, 5, yappCoordBox] 
];
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

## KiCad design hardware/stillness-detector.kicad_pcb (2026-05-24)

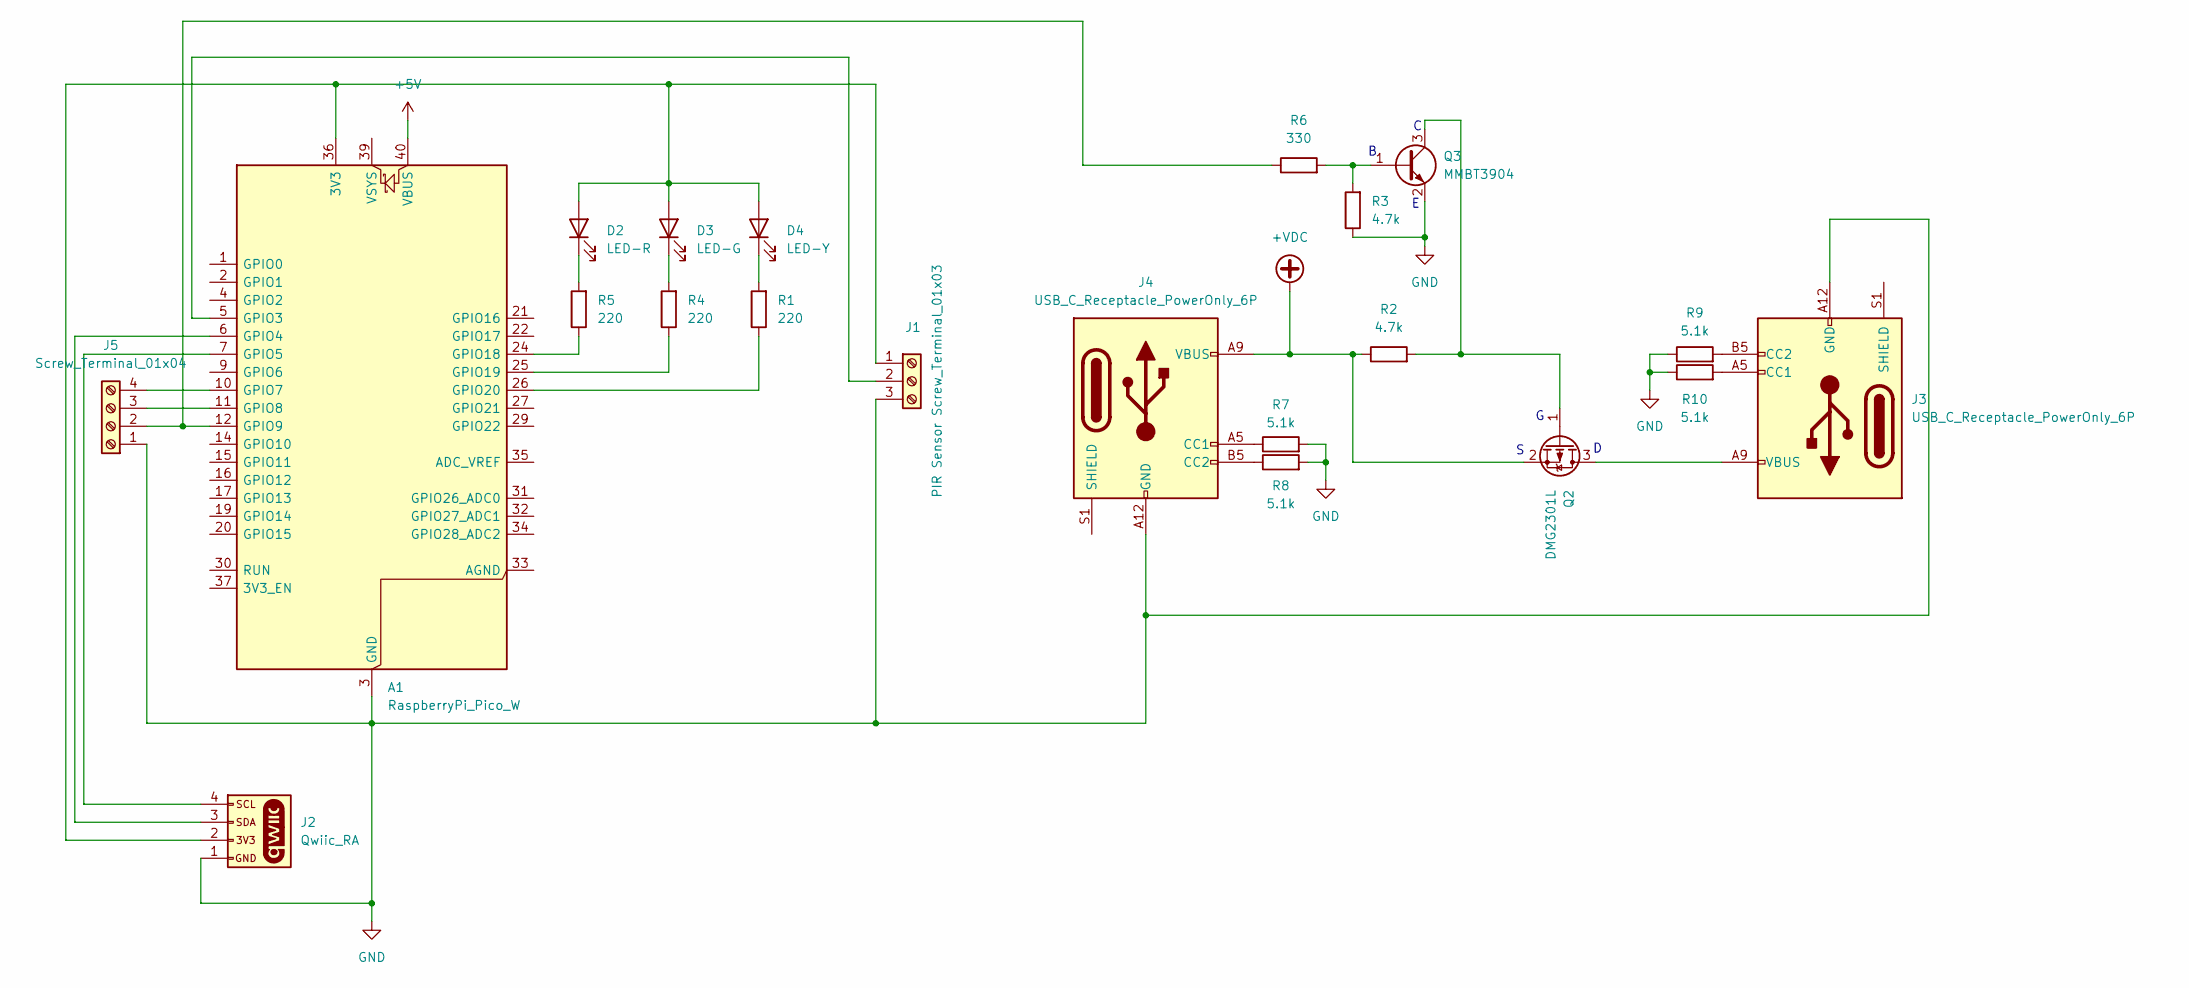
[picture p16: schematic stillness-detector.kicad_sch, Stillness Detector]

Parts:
A1: RaspberryPi_Pico_W; RaspberryPi_Pico_Common_Unspecified
D2: LED-R; LED_1206_3216Metric
D3: LED-G; LED_1206_3216Metric
D4: LED-Y; LED_1206_3216Metric
J1: PIR Sensor Screw_Terminal_01x03; TerminalBlock_Xinya_XY308-2.54-3P_1x03_P2.54mm_Horizontal
J2: Qwiic_RA; JST_1x04_P1.0mm_Horizontal_SMD
J3, J4: USB_C_Receptacle_PowerOnly_6P; USB_C_Receptacle_GCT_USB4125-xx-x-0190_6P_TopMnt_Horizontal
J5: Screw_Terminal_01x04; TerminalBlock_Xinya_XY308-2.54-4P_1x04_P2.54mm_Horizontal
Q2: DMG2301L; SOT-23
Q3: MMBT3904; SOT-23
R1, R4, R5: 220; R_1206_3216Metric
R2, R3: 4.7k; R_1210_3225Metric_Pad1.30x2.65mm_HandSolder
R6: 330; R_1210_3225Metric_Pad1.30x2.65mm_HandSolder
R7, R8, R9, R10: 5.1k; R_1210_3225Metric_Pad1.30x2.65mm_HandSolder

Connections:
+5V: A1.40 (VBUS)
+VDC: J4.A9 (VBUS), J4.B9 (VBUS), Q2.2 (S), R2.1
GND: A1.3 (GND), A1.8 (GND), A1.13 (GND), A1.18 (GND), A1.23 (GND), A1.28 (GND), A1.38 (GND), J1.3, J2.1, J3.A12 (GND), J3.B12 (GND), J4.A12 (GND), J4.B12 (GND), J5.1, Q3.2 (E), R3.1, R7.2, R8.2, R9.1, R10.1
unnamed: A1.36 (3V3), D2.2 (A), D3.2 (A), D4.2 (A), J1.1, J2.2
unnamed: A1.5 (GPIO3), J1.2
unnamed: A1.6 (GPIO4), J2.3
unnamed: A1.7 (GPIO5), J2.4
unnamed: A1.10 (GPIO7), J5.4
unnamed: A1.11 (GPIO8), J5.3
unnamed: A1.12 (GPIO9), J5.2, R6.1
unnamed: A1.24 (GPIO18), R5.1
unnamed: A1.25 (GPIO19), R4.1
unnamed: A1.26 (GPIO20), R1.1
unnamed: D2.1 (K), R5.2
unnamed: D3.1 (K), R4.2
unnamed: D4.1 (K), R1.2
unnamed: J3.A5 (CC1), R10.2
unnamed: J3.B5 (CC2), R9.2
unnamed: J4.A5 (CC1), R7.1
unnamed: J4.B5 (CC2), R8.1
unnamed: J3.A9 (VBUS), J3.B9 (VBUS), Q2.3 (D)
unnamed: Q2.1 (G), Q3.3 (C), R2.2
unnamed: Q3.1 (B), R3.2, R6.2

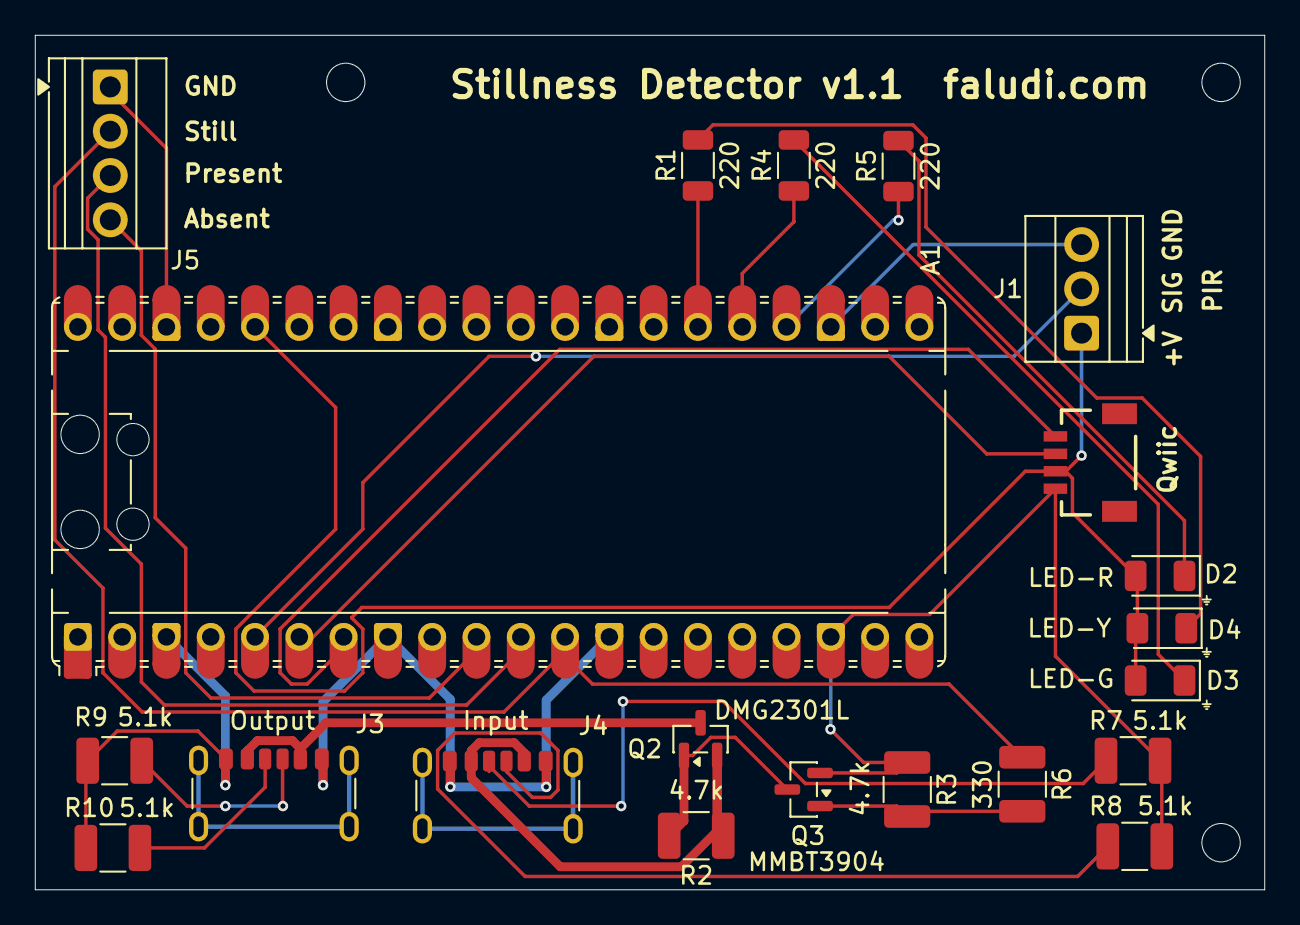
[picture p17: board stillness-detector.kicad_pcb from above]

Board: 2 copper layers, 70.5 x 49.0 mm, 21 parts (0 on the bottom side), 22 nets.

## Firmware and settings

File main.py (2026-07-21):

# Requires time of flight sensor driver: https://github.com/drakxtwo/vl53l1x_pico

from machine import Pin, I2C
from vl53l1x import VL53L1X
import time
import sys
import settings

time.sleep(2) # allow usb connection on startup

# TODO: Add optional power-saving features for battery operation

version = "1.0.19"
print("Stillness Detector - Version:", version)

# Pin Assignments
PIR_PIN = 3
STATUS_LED_PIN = "LED"
RED_LED_PIN = 18
GREEN_LED_PIN = 19
YELLOW_LED_PIN = 20
ABSENT_OUTPUT_PIN = 7
PRESENT_OUTPUT_PIN = 8
STILL_OUTPUT_PIN = 9
USB_CONTROL_PIN = 10

# LED States (for clarity)
LED_ON = 0  # Active low
LED_OFF = 1

PIR_RESET_TIME = settings.PIR_RESET_TIME
MAX_DISTANCE = settings.MAX_DISTANCE
MIN_DISTANCE = settings.MIN_DISTANCE

MODE = settings.MODE

MODE_PRESETS = {
    "relaxed": {"settling_delay": 3, "damping_interval": 3, "allowable_distance_change": 1000},
    "normal": {"settling_delay": 5, "damping_interval": 7, "allowable_distance_change": 300},
    "strict": {"settling_delay": 10, "damping_interval": 20, "allowable_distance_change": 200},
}

if MODE in MODE_PRESETS:
    config = MODE_PRESETS[MODE]
    SETTLING_DELAY = config["settling_delay"]
    DAMPING_INTERVAL = config["damping_interval"]
    ALLOWABLE_DISTANCE_CHANGE = config["allowable_distance_change"]
elif MODE == "custom":
    SETTLING_DELAY = settings.SETTLING_DELAY
    DAMPING_INTERVAL = settings.DAMPING_INTERVAL
    ALLOWABLE_DISTANCE_CHANGE = settings.ALLOWABLE_DISTANCE_CHANGE
else:
    print("Invalid MODE in settings.py")
    sys.exit(1)

# Initialize I2C and Time-of-Flight sensor with retries
attempts = 0
while attempts < 3:
    try:
        i2c = I2C(0)
        time_of_flight = VL53L1X(i2c)
        break
    except Exception as e:
        attempts += 1
        print("Attempt", attempts, "to initialize VL53L1X failed:", e)
        time.sleep(1)
    if attempts == 3:    
        print("Failed to initialize VL53L1X:")
        sys.exit(1)

class HardwareInterface:
    """
    Manages all hardware components for the stillness detector.
    
    This class encapsulates the setup and control of:
    - Motion sensor (PIR)
    - Status LED (onboard)
    - RGB LED indicator
    - Digital output pins for external devices
    
    All LEDs are configured as active-low (0=on, 1=off).
    """
    def __init__(self):
        self.motion_sensor = Pin(PIR_PIN, Pin.IN)
        self.status_led = Pin(STATUS_LED_PIN, Pin.OUT)
        self.rgb_leds = {
            "red": Pin(RED_LED_PIN, Pin.OUT),
            "green": Pin(GREEN_LED_PIN, Pin.OUT),
            "yellow": Pin(YELLOW_LED_PIN, Pin.OUT),
        }
        self.outputs = {
            "absent": Pin(ABSENT_OUTPUT_PIN, Pin.OUT),
            "present": Pin(PRESENT_OUTPUT_PIN, Pin.OUT),
            "still": Pin(STILL_OUTPUT_PIN, Pin.OUT),
            "usb_control": Pin(USB_CONTROL_PIN, Pin.OUT),
        }
        self._initialize_all()
    
    def _initialize_all(self):
        self.status_led.value(LED_OFF)
        for led in self.rgb_leds.values():
            led.value(LED_OFF)  # LEDs are active-low, so 1=off
        for output in self.outputs.values():
            output.value(0)
    
    def set_rgy_led(self, red, green, yellow):
        self.rgb_leds["red"].value(red)
        self.rgb_leds["green"].value(green)
        self.rgb_leds["yellow"].value(yellow)
    
    def get_motion(self):
        return self.motion_sensor.value()

# Initialize hardware
hardware = HardwareInterface()

class StillnessDetector:
    """
    Detects if a person is present and still using distance and motion sensors.
    
    States:
    - "absent": No person detected (distance out of range)
    - "present": Person detected but moving
    - "still": Person detected and still for the settling delay duration
    """
    def __init__(self, max_distance=1500, min_distance=50, delay=2, damping_interval=10):
        self.max_distance = max_distance
        self.min_distance = min_distance
        self.delay = delay
        self.presence_start_time = None
        self.elapsed_time = 0
        self.stillness_detected = False
        self.movement_dampening_interval = damping_interval
        self.last_motion_time = time.time()
        self.start_distance = None

    def is_person_detected(self, distance):
        # Check if distance reading is valid and within thresholds
        return distance is not None and self.min_distance < distance < self.max_distance
    
    def get_status(self):
        # Returns "still" if stillness detected, "present" if presence detected but not still, and "absent" if no presence detected
        if self.stillness_detected:
            return "still"
        elif (self.presence_start_time is not None):
            return "present"
        else:
            return "absent"
    
    def update(self, distance, motion):
        if not self.is_person_detected(distance):
            self.reset()
            return
        
        # Handle initial detection
        if self.presence_start_time is None:
            self._handle_initial_detection(distance)
            return
        
        # Check for significant movement
        self._check_distance_change(distance)
        
        # Update elapsed time and check stillness
        self.elapsed_time = time.time() - self.presence_start_time
        self._update_stillness_status(motion)
    
    def _handle_initial_detection(self, distance):
        self.presence_start_time = time.time()
        self.last_motion_time = time.time()
        self.start_distance = distance
        print("Distance threshold crossed, starting timer")
    
    def _check_distance_change(self, distance):
        if abs(distance - self.start_distance) > ALLOWABLE_DISTANCE_CHANGE:
            print("Significant distance change detected, resetting timer")
            self.reset()
            self._handle_initial_detection(distance)
    
    def _update_stillness_status(self, motion):
        # Clearer logic for motion/stillness determination
        if self.elapsed_time <= self.delay:
            print("Waiting for settling delay...")
        elif motion == 0:  # No motion
            self.stillness_detected = True
            print(f"Person has been still for {self.elapsed_time:.1f} seconds")
        else:  # Motion detected
            self._handle_motion_detected()
    
    def _handle_motion_detected(self):
        if time.time() - self.last_motion_time > self.movement_dampening_interval:
            self.last_motion_time = time.time()
            print("Ignoring brief motion")
        elif time.time() - self.last_motion_time < PIR_RESET_TIME:
            print("PIR reset time not yet elapsed, ignoring motion")
        else:
            print("Person is in motion")
            self.reset()

    def reset(self):
        # Reset all timers and flags
        self.presence_start_time = None
        self.elapsed_time = 0
        self.start_distance = None
        self.stillness_detected = False
    
    def set_max_distance(self, threshold):
        self.max_distance = threshold
        print("Max distance set to:", threshold)

    def set_min_distance(self, threshold):
        self.min_distance = threshold
        print("Min distance set to:", threshold)

    def set_delay(self, delay):
        # Set the required stillness duration before detection is triggered
        self.delay = delay
        print("Delay set to:", delay)

    def get_distance(self):
        # Get current distance reading from time-of-flight sensor
        return self.max_distance
    
    def get_motion(self):
        # Get current motion state from PIR sensor
        return hardware.get_motion()

def read_distance():
    try:
        distance = time_of_flight.read()
        if distance == 0:
            print("Error: Invalid distance reading (0 mm)")
            return None
        return distance
    except Exception as e:
        print(f"Error reading distance: {e}")
        return None
    
def blink_led(pin, times, interval=0.2):
    for _ in range(times):
        pin.on()
        time.sleep(interval)
        pin.off()
        time.sleep(interval)

# Initialize the stillness detector with configured parameters
detector = StillnessDetector(max_distance=MAX_DISTANCE, min_distance=MIN_DISTANCE, delay=SETTLING_DELAY, damping_interval=DAMPING_INTERVAL)

# Main loop to read distance every second
def main():
    while True:
        # Provide visual feedback on status LED based on recent motion activity
        if time.time() - detector.last_motion_time < DAMPING_INTERVAL:
            blink_led(hardware.status_led, 2, interval=0.1)
        else:
            blink_led(hardware.status_led, 1, interval=0.2)
        # Read distance and motion sensor values, update stillness detector
        distance = read_distance()
        motion_state = hardware.get_motion()
        print("Distance (mm):", distance, "PIR State:", motion_state)
        detector.update(distance, motion_state)
        # Set LED and output pins based on stillness status
        if detector.get_status() == "still":
            hardware.set_rgy_led(1, 0, 1)  # Green for stillness detected
            hardware.outputs["still"].value(1)
            hardware.outputs["present"].value(0)
            hardware.outputs["absent"].value(0)
            hardware.outputs["usb_control"].value(1)  # Activate USB control when stillness is detected

        elif detector.get_status() == "present":
            hardware.set_rgy_led(1, 1, 0)  # Yellow for presence detected
            hardware.outputs["still"].value(0)
            hardware.outputs["present"].value(1)
            hardware.outputs["absent"].value(0)
            hardware.outputs["usb_control"].value(0)  # Deactivate USB control when presence is detected
        else:
            hardware.set_rgy_led(0, 1, 1)  # Red for no presence detected
            hardware.outputs["still"].value(0)
            hardware.outputs["present"].value(0)
            hardware.outputs["absent"].value(1)
            hardware.outputs["usb_control"].value(0)  # Deactivate USB control when no presence is detected
        time.sleep(0.5) # Short delay to prevent excessive sensor reads and allow for visual feedback on status LED

if __name__ == "__main__":
    try:
        main()
    except KeyboardInterrupt:
        # Gracefully handle Ctrl+C to exit the program
        print("Program interrupted by user")
        hardware.status_led.value(0)
        for led in hardware.rgb_leds.values():
            led.value(1)
        sys.exit(0)

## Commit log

2026-01-19 replace ultrasonic sensing with tof
    [main.py]
2026-01-22 add stillness detector class, RGB leds, delays
2026-01-30 replace None test in update()
    [main.py]
2026-01-30 add settings and reset function if TOF fails
    [main.py]
2026-03-10 Improvements to PIR stability with pulldown and new damping logic
    [main.py]
2026-03-11 Add diagrams and BOM to readme
2026-03-11 Improve detection and change out a BOM part
2026-03-21 Change common cathode to common annode RGY LED.
2026-05-05 add docstring and rename led setting to match colors
2026-05-15 bugfixes and reversion to LED sink
    [main.py]
2026-05-24 add hardware assets
    [Stillness Detector BOM.xlsx, Stillness_Detector_Enclosure_v1.0.scad, Stillness_Detector_Enclosure_v1.0.stl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]
2026-07-21 Adds a separate pin for USB-C power control, returning stillness output to full 3.3V
